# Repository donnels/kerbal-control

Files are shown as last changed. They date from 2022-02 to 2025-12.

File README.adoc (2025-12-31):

= image index
:toc:
[[2022-02-18T14-46%3A09-576Z.png]]

.2022-02-18T14-46%3A09-576Z.png

[[ISP_Voltage.png]]
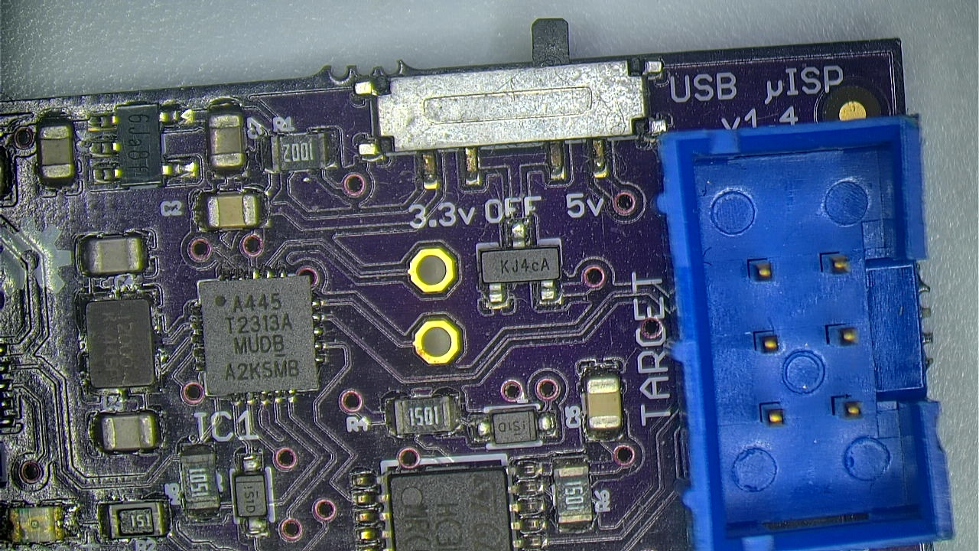
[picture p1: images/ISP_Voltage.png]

.ISP_Voltage.png

[[ISP_pinout.png]]
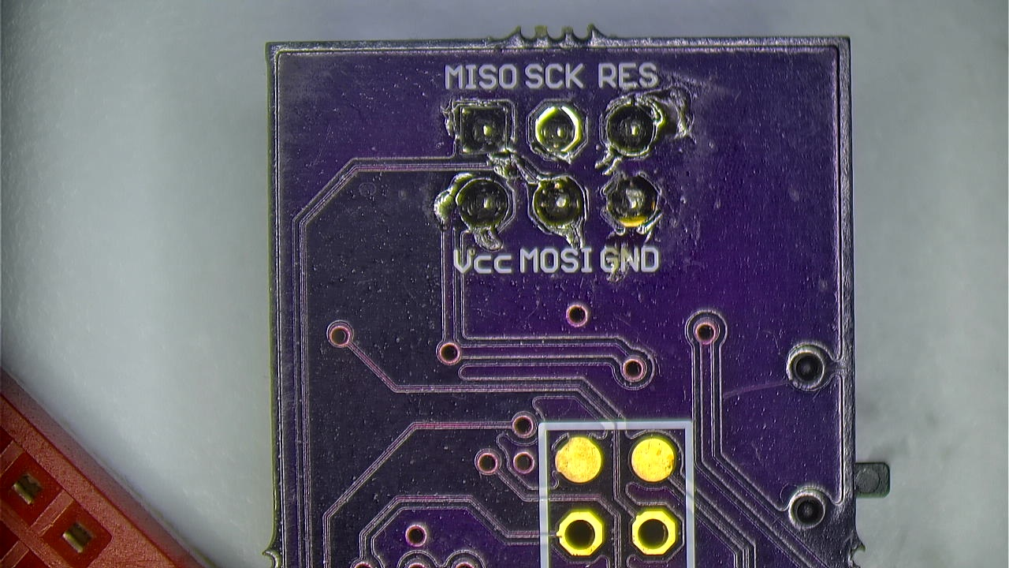
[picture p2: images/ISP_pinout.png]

.ISP_pinout.png

[[Kerbal.png]]
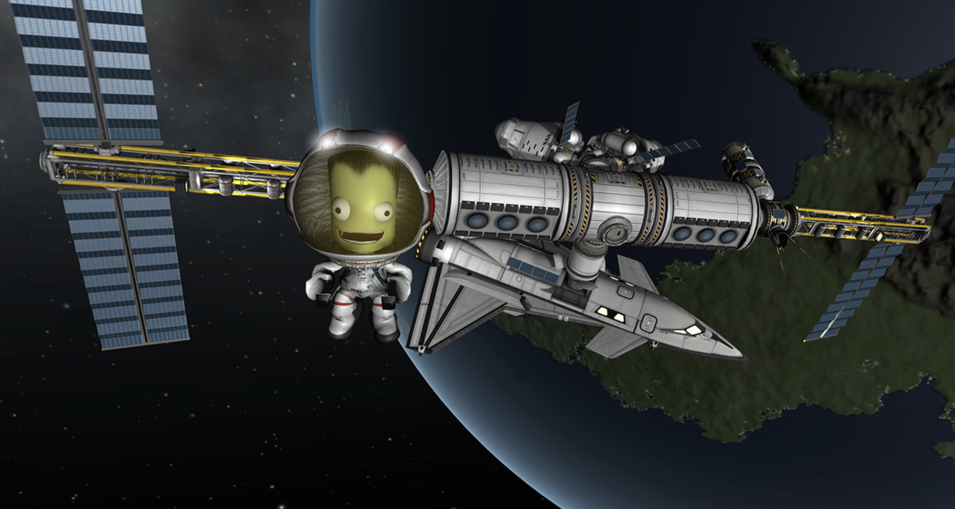
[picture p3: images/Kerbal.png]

.Kerbal.png

[[arduino-pro-micro-5v-pinout.png]]
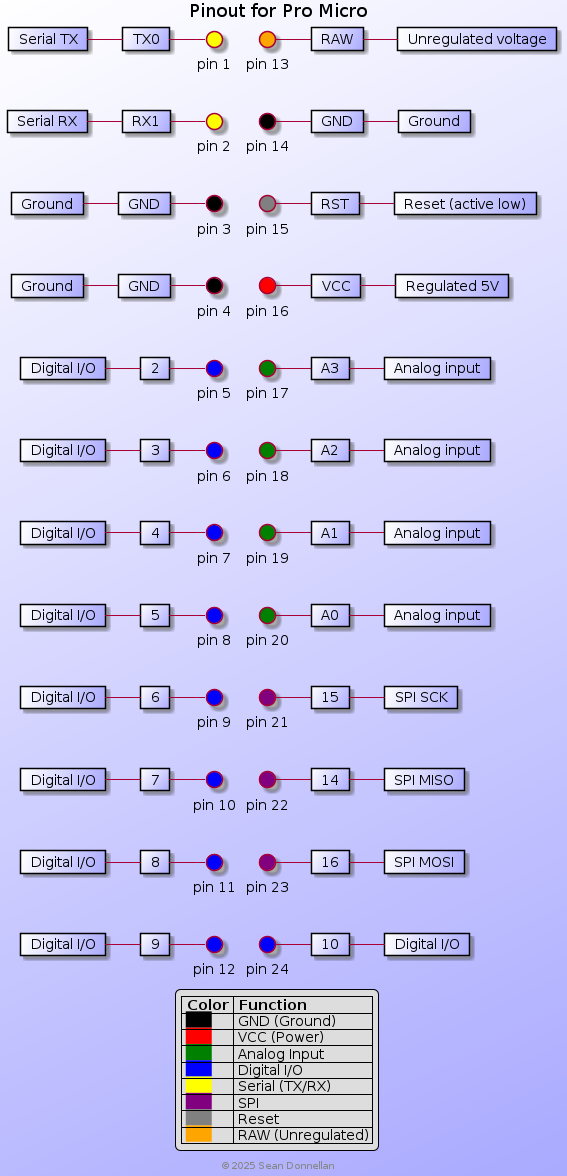
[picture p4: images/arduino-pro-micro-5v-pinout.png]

.arduino-pro-micro-5v-pinout.png

[[arduino-pro-micro-5v.png]]
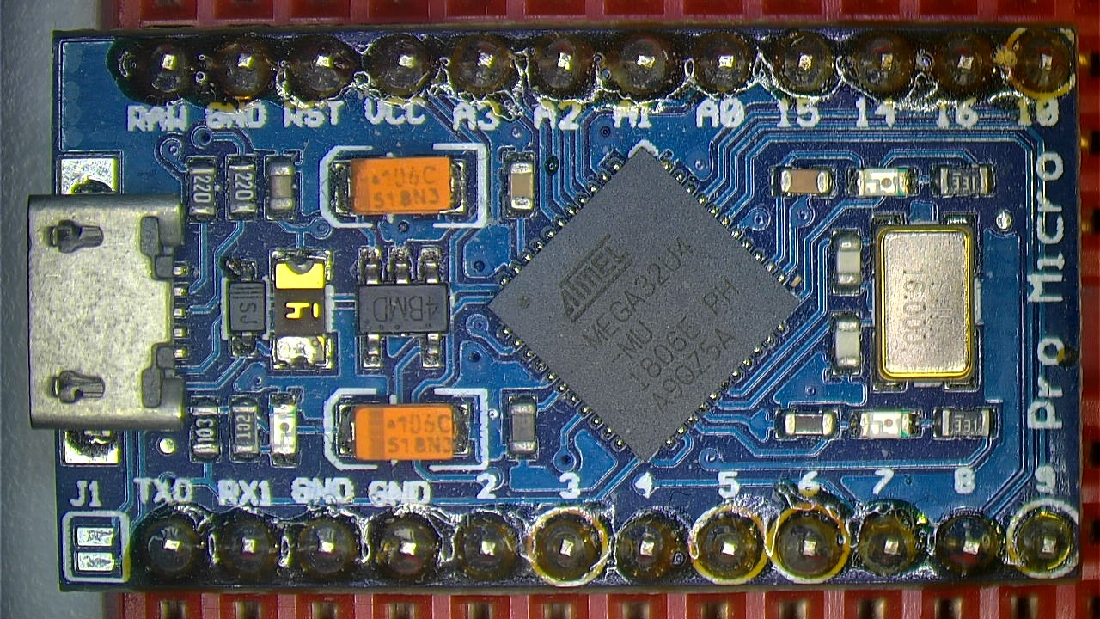
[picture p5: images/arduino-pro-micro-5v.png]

.arduino-pro-micro-5v.png

[[arduino-pro_micro_isp_schematic.png]]
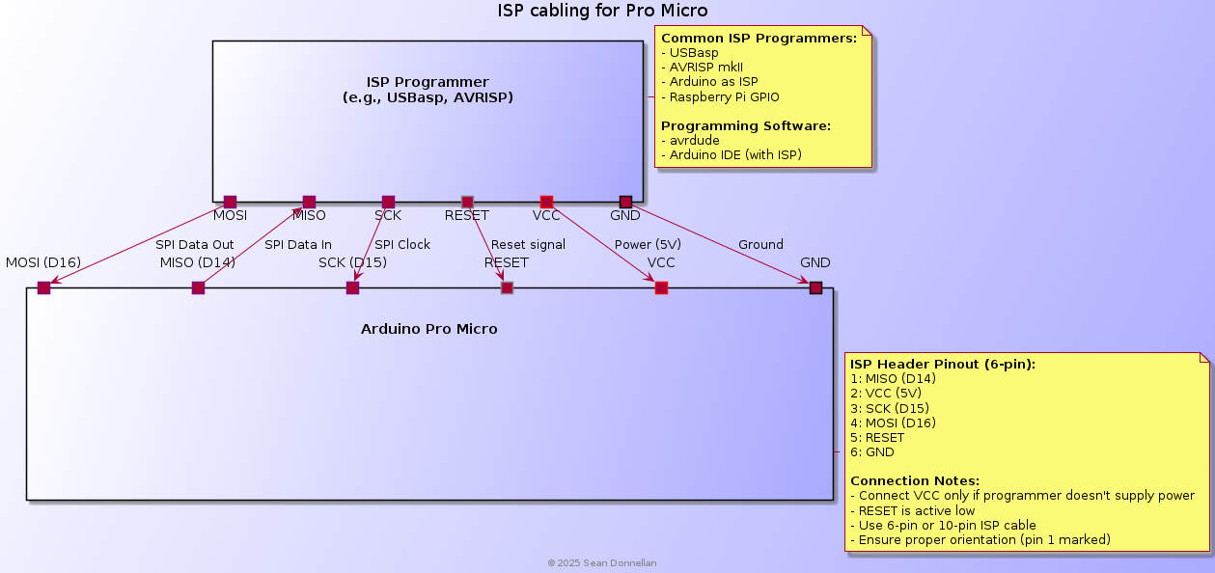
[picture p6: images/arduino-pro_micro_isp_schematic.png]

.arduino-pro_micro_isp_schematic.png

[[bounce.png]]
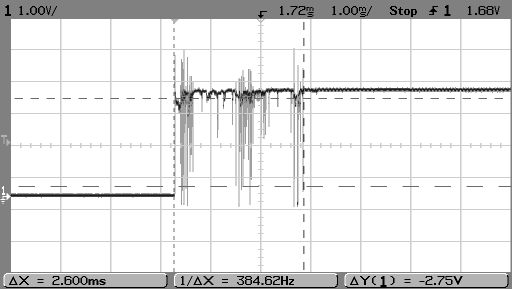
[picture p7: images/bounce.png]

.bounce.png

[[cherry-keycap-holder.png]]
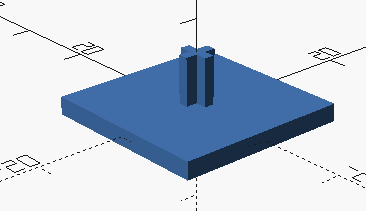
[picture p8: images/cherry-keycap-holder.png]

.cherry-keycap-holder.png

[[debounce.png]]
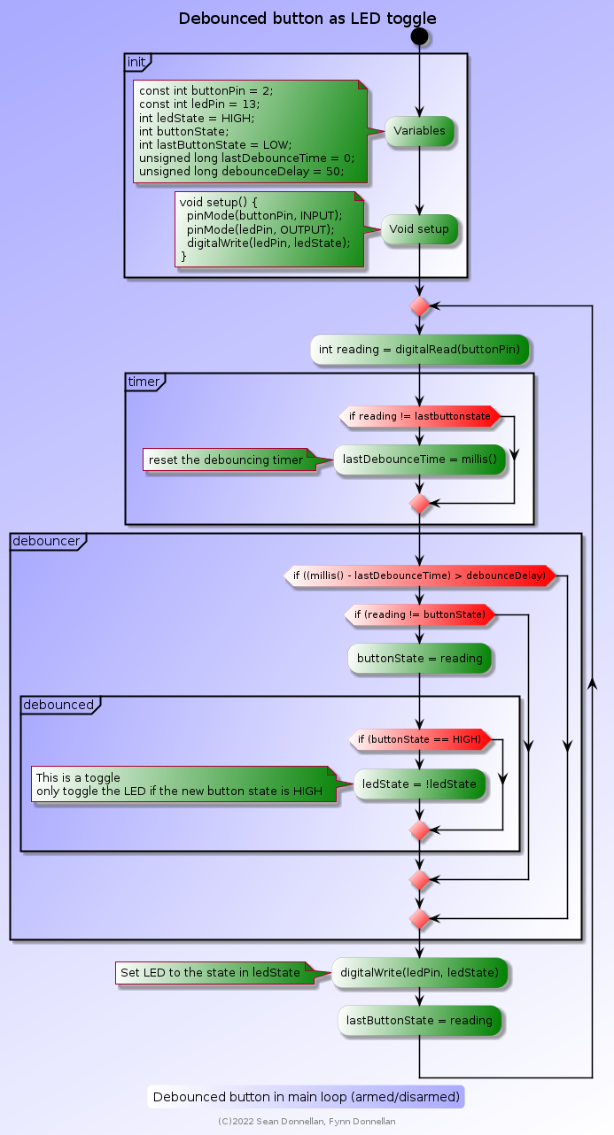
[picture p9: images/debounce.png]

.debounce.png

[[debounce2.png]]
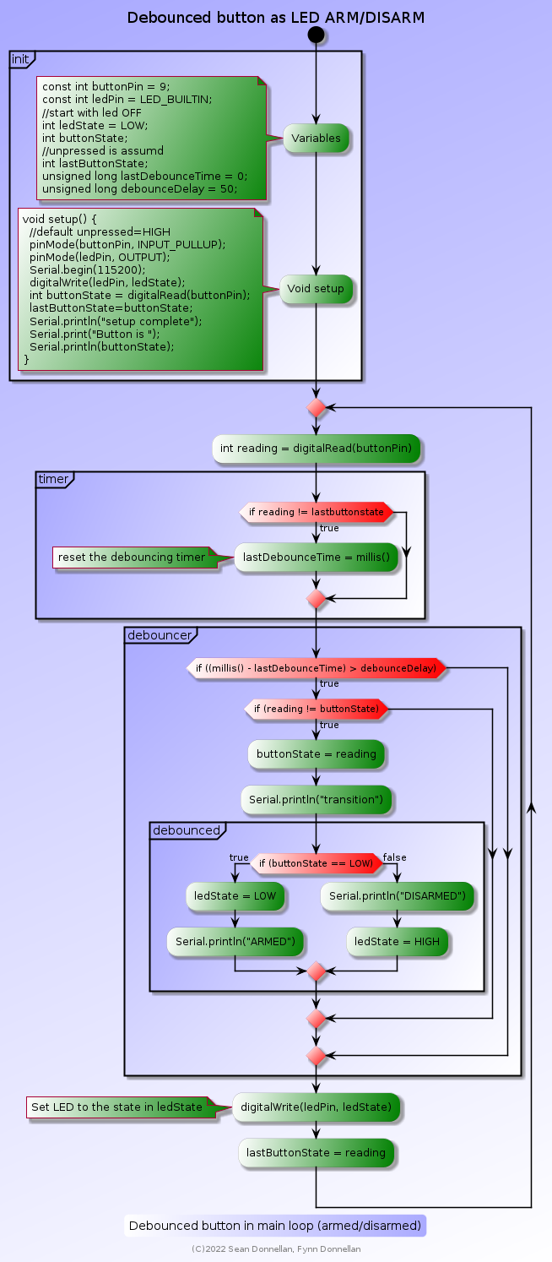
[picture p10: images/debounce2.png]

.debounce2.png

[[resistor-10kohm.png]]
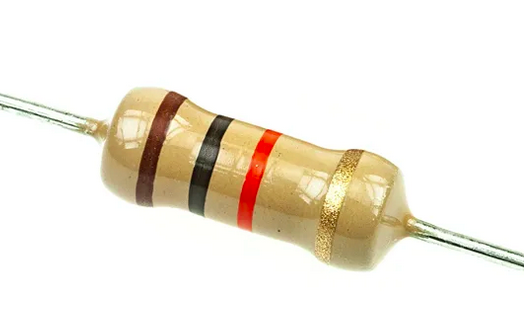
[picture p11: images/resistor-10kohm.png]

.resistor-10kohm.png

[[Button-Triger-stage.jpeg]]
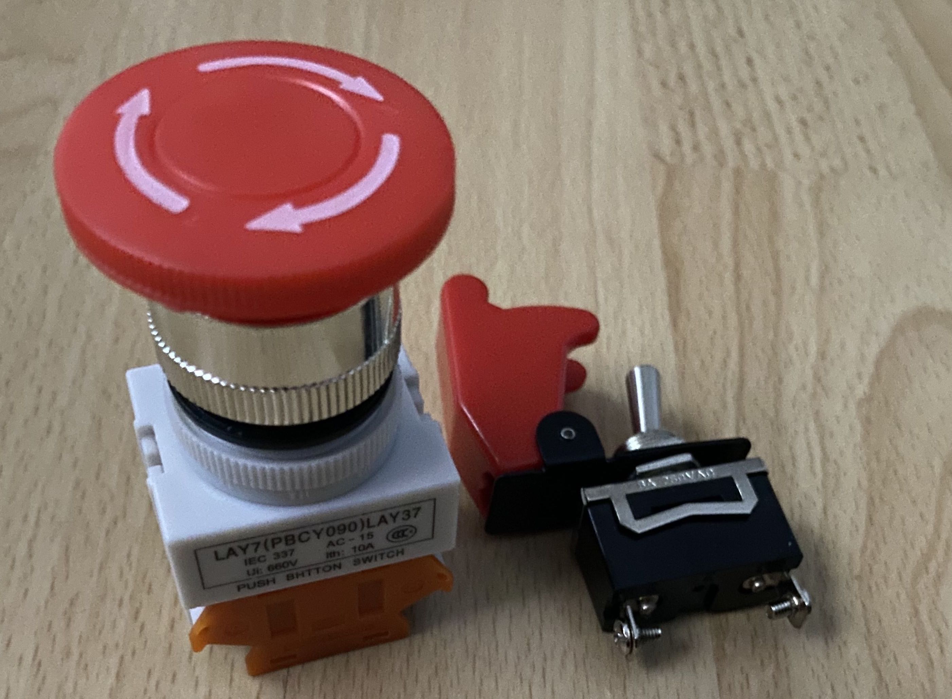
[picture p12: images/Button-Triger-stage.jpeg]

.Button-Triger-stage.jpeg

[[Prototype-led-ring-and-strip.jpeg]]
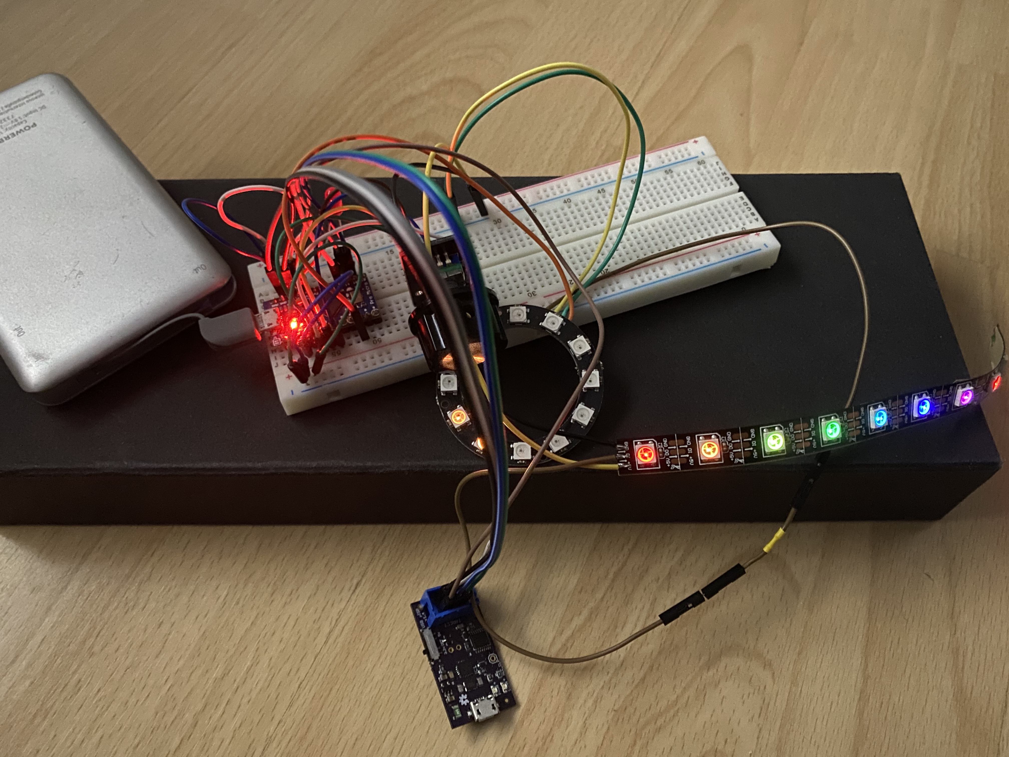
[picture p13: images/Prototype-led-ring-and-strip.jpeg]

.Prototype-led-ring-and-strip.jpeg

[[keyAndCapMokup.jpeg]]
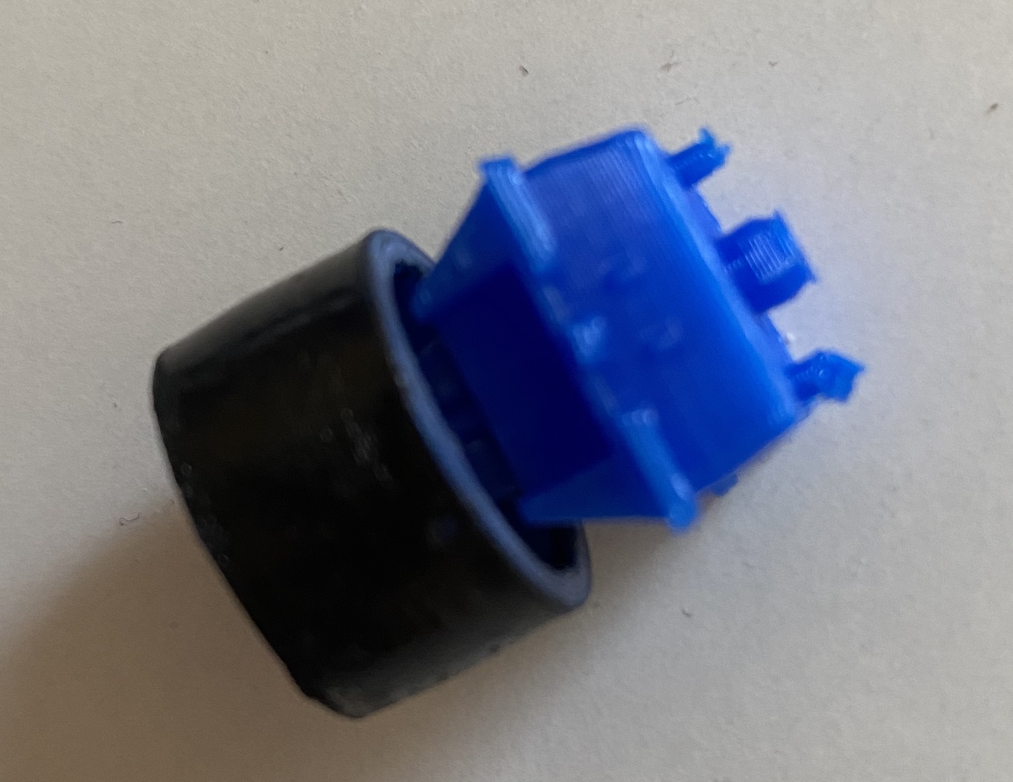
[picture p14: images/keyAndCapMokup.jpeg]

.keyAndCapMokup.jpeg

[[keycap-sanded.jpeg]]
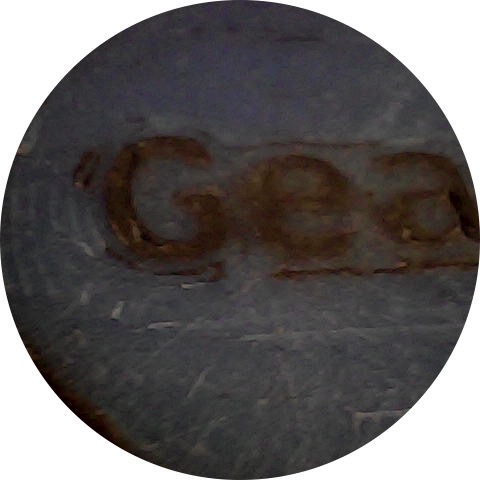
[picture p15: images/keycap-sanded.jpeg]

.keycap-sanded.jpeg

[[keycaps.jpeg]]
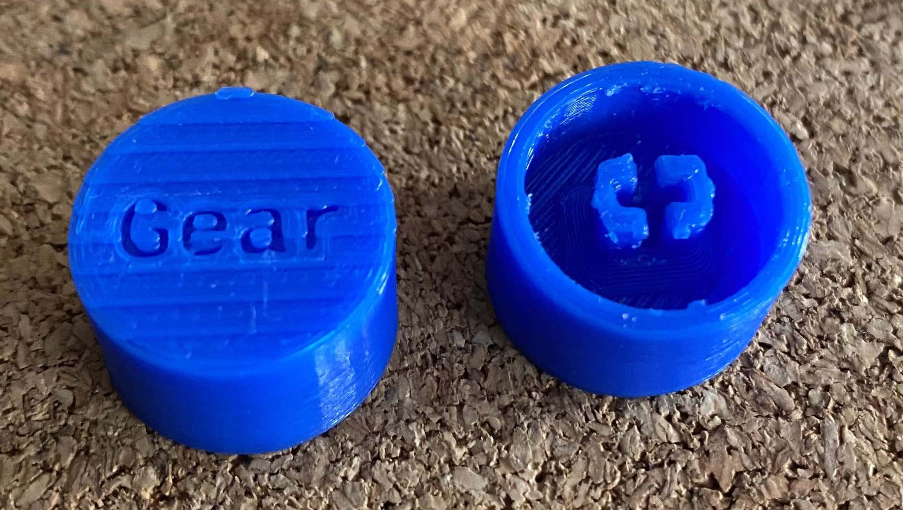
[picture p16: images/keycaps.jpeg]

.keycaps.jpeg

[[sand-paint-sand.jpeg]]
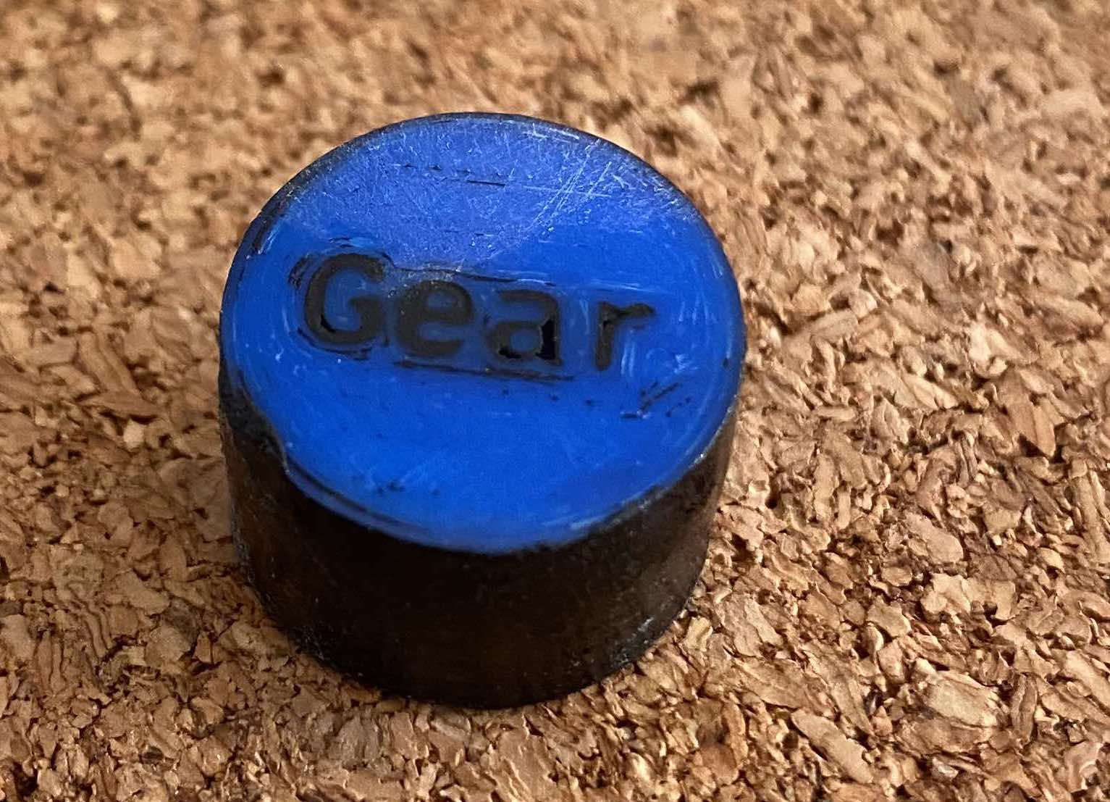
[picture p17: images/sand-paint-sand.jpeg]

.sand-paint-sand.jpeg

[[v2PlusButtons.jpeg]]
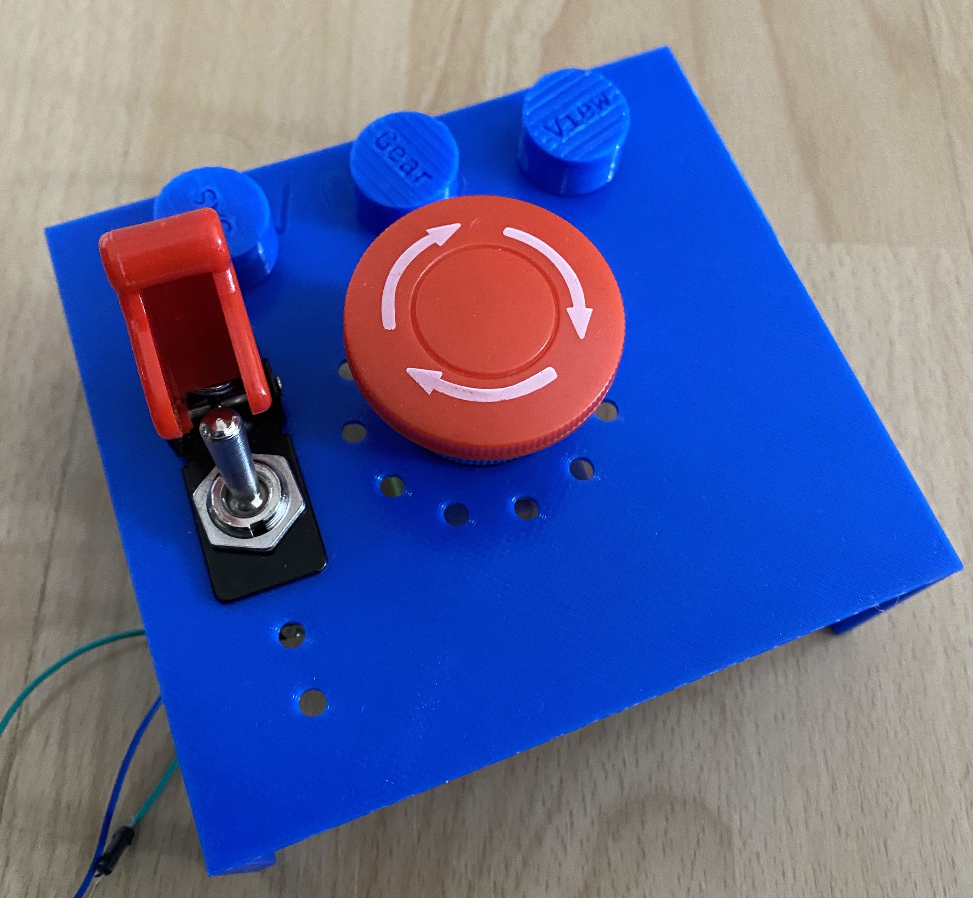
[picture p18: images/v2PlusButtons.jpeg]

.v2PlusButtons.jpeg

[[arduino-pro-micro-5v-pinout.svg]]

.arduino-pro-micro-5v-pinout.svg

[[arduino-pro_micro_isp_schematic.svg]]

.arduino-pro_micro_isp_schematic.svg

[[debounce.svg]]

.debounce.svg

[[debounce2.svg]]

.debounce2.svg

[[kerbal_ctrl_box_prototype.svg]]

.kerbal_ctrl_box_prototype.svg

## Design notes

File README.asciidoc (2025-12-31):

= kerbal-control
:author: Sean Donnellan, Oscar Donnellan, Fynn Donnellan
:toc: right
:sectnums:
:sectnumlevels: 5
:toclevels: 5
:data-uri: false
:doctype: article
:icons: font
:pdf-page-size: A4
:source-highlighter: rouge
:title-page:

== About this document

.HTML version
* link:https://donnels.github.io/kerbal-control/README.html[^]

.PDF version
* link:https://donnels.github.io/kerbal-control/README.pdf[^]

.Github source
* link:https://github.com/donnels/kerbal-control[^]

== Starting point
A project to add some more control to the PS5 Kerbal simulation.

.Screenshot from www.kerbalspaceprogram.com


* link:https://www.kerbalspaceprogram.com/[^]

After installing Kerbal on the PS5 and playing it for a while it quickly became clear that the controllers alone are not enough to enjoy the game.
The search began to find some way of improving things.
Kerbal allows control via the PS5 controllers AND via keyboard and mouse.
This means it should be possible to add some easy toggles/ switches/ rotary encoders to pass information to the game.
The first switch would be the space bar which kerbal uses to trigger stages.

While this is being developed for Kerbal it is generally a keyboard and can just as easily be used for many other applications, including video conferences.

=== kerbal key bindings
The following is a list of key bindings we can work with.

.Key bindings for Kerbal
* link:https://wiki.kerbalspaceprogram.com/wiki/Key_bindings[^]

The first key will be the space key to launch rockets.

=== Arduino - pro micro (5V)
Initial choice for a prototype is the AVR ATmega32u4 8-bit microcontroller which has a USB controller and can be used as both a keyboard and mouse if required.

"The Pro Micro is an Arduino-compatible microcontroller board developed under an open hardware license by Sparkfun. Clones of the Pro Micro are often used as a lower-cost alternative to a Teensy 2.0 as a basis for a DIY keyboard controller/converter when a lower number of pins would suffice."
-- https://deskthority.net/wiki/Arduino_Pro_Micro

.Pro micro 5v board


.Pro Micro Pinout


.Pro Micro ISP connections


The above figure shows the connections required to program the pro micro via ISP if the usb programming is failing.

[IMPORTANT]
====
During ISP programming, the Pro Micro board requires external power. Connect the board to a USB power source (computer, wall adapter, etc.) as the Raspberry Pi Zero does not provide sufficient power through the ISP programmer alone. Without external power, you may see "device signature = 0x000000" errors.
====

[NOTE]
====
When you have one or two different ones floating around it's easy to forget which is which. Measure the voltage between GND and VCC, with USB powered up, to be sure you have the 5V version. Don't let the magic smoke out by connecting the wrong voltage.
====

=== WS2812 LEDs
Because it's always good to have status LEDs and the WS2812 is both easy to get and has good libraries, with fastled and adafruit, it's the first choice. 

.Fastled
* link:https://github.com/FastLED/FastLED[^]
* link:https://fastled.io/[^]

The fastled library looks like a good choice.
The WS2812 LED rings I have are not tightly packed with LEDs but will suffice.
As I have a few WS2812 strips and a few WS2812 rings the choice went towards the WS2812 to be able to mix the strip and ring. In a first test I had accidentally used an RGBW ring which showed up that the fastled library can't handle them well so WS2812 is the choice now.

== Step 1 - First prototype
To get started I went to an example for LEDs to be able to later set a LED with a key/button.

.First LED example (arduino IDE)
[source%linenums, c++]
----
include::./src/fastled-test/fastled-test.ino[]
----

[NOTE]
====
The first test looks good and was tested on a 5v pro micro.
The prototype uses a strip with ten LEDs attached to a ring with 12 LEDs.
====

.Initial breadboard prototype with WS2812 ring and strip


The above code runs a LED around the ring and sets static colours on the strip.
A good start.
The animation works with delay which is probably not a good solution but works fine for a first test.

== Step 2 - Attach a button to trigger a stage

Since this will be starting rockets let's make it feel that way.
Just the space bar and maybe a toggle to arm it.

.Arduino reference
* keyboard
** link:https://www.arduino.cc/reference/en/language/functions/usb/keyboard/[^]
* Button
** link:https://www.arduino.cc/en/Tutorial/BuiltInExamples/Button[^]
* State change detection
** link:https://www.arduino.cc/en/Tutorial/BuiltInExamples/StateChangeDetection[^]

.Resistor for pull down

We will need to pull down/up the pin for the button so the above resistor is included to show an example 10K Ohm resistor. The pro micro may have inbuilt pull up/down resistors but that has to be checked. Pulling a line up or down endures it is always in a defined state and that it reacts quickly so that it is highly recommended even for testing.

.first buttons


The big red button is to trigger a stage and the toggle switch is to arm it. In this case we will soft arm the bitton as opposed to disconnecting it directly. 

.Very draft UI design


=== Bouncy Bouncy
Why all the fuss about bounce? And what is it?

* link:https://en.wikipedia.org/wiki/Switch[^]

.Example of bounce from the wikipedia


.activity diagram to show the flow


==== Interrupts
"The Pro Micro has five external interrupts, which allow you to instantly trigger a function when a pin goes either high or low (or both). If you attach an interrupt to an interrupt-enabled pin, you'll need to know the specific interrupt that pin triggers: pin 3 maps to interrupt 0 (INT0), pin 2 is interrupt 1 (INT1), pin 0 is interrupt 2 (INT2), pin 1 is interrupt 3 (INT3), and pin 7 is interrupt 4 (INT6)."
-- https://learn.sparkfun.com , pro micro hookup guide

.Example interrupt driven routine debounced
[source%linenums, c++]
----
void my_interrupt_handler()
{
  static unsigned long last_interrupt_time = 0;
  unsigned long interrupt_time = millis();
  // If interrupts come faster than 200ms, assume it's a bounce and ignore
  if (interrupt_time - last_interrupt_time > 200)
  {
    ... do your thing
  }
  last_interrupt_time = interrupt_time;
}
----

The above short section shows a debounced interrupt that uses millis instead of delays.
The important thing here is that if we debounce with delays we stall the whole loop so that if we have a LED animation or something else running it get's stalled. Using millis allows the rest to keep running.

Let's see if some of the above works.

=== first iteration
.initial tests
[source%linenums, c++]
----
include::./src/button-test/button-test.ino[]
----

[NOTE]
====
The first test looks good and was tested on an arduino UNO.
====

The above code works as a debounced latching button.
The aim though is to read a debounced button and to read it's state changes.

.What we really need
* ONLY when the button is pressed
** output state ONCE
* When button is released
** Output state once

=== Second iteration

.activity diagram to show the flow


.Second button test non latching (armed/disarmed)
[source%linenums, c++]
----
include::./src/button-test2/button-test2.ino[]
----

[NOTE]
====
This works and it was tested on an arduino uno.
Serial monitor was used to check the function.
====

== Step 3 - bring things together to see how the loop runs with buttons

.Integrated controller with LEDs, arm/disarm button, and stage button
[source%linenums, c++]
----
include::./src/kerbal-controller/kerbal-controller.ino[]
----

This MVP integrates LEDs for status, debounced buttons, and keyboard emulation for staging.

== Step 4 - rotary encoders

.An initial example with interrupts
* link:https://gist.github.com/dkgrieshammer/66cce6ec92a6427c16804df84c22cc83[^]

[appendix]
== Requirements

.Initial list of requirements
* Control Kerbal on PS5
** Via USB(A) keyboard interface
*** Use big red button with latch for stages
** Must show actions/button presses
*** WS2812 for key status changes red/green/etc
** Add some safety toggles (arm/disarm)
*** A classic toggle with red cover
** Control 
*** Stage trigger (space bar)
*** SAS (on/off) (t)
*** gear (up/down) (g)
*** time warp (rotary +/-) (.,)
*** throttle (rotary +/-) (shift,cntrl)
*** motors (on/off) (x,k)
*** View (inside/outside) ???

This should cover the most required buttons and should be possible without multiplexing.

[appendix]
== Interface design thoughts
Since the first button is a big red one with a latch it make sense to also show what state it's in.
Adding a LED ring around it sounds like a good idea.
Adding a LED ring around a rotary encoder also sounds like a good idea (optional).

=== Arm/disarm toggle
toggle disarmed:: disArm led LED red(?), latch ring red blink(?)
toggle armed:: ARM led green, latch ring green

=== Triger stage button
unlatched:: ring green
press:: ring red for 1 sec
latched:: Ring orange

[appendix]
== 3d printed test stand
The Aim here is to have a stand to mount the buttons and LEDs to while testing.
After testing this can be used as a template for drilling.
Also this can later be adapted to make a holder for the led ring and potentially the LEDs that can be mounted under the lid of the box.

.OpenScad source
[source%linenums,openscad]
----
include::./3d/protoTypeStand.scad[]
----

.3d stand STL (second iteration)
image::./3d/Screenshot 2022-02-07 at 20.28.38.png[]

The first test fitting worked well to show up some room for improvement:

* Toggle switch moved left and down
* legs longer
* LED ring proper Radius

.Prototype with v2


The intial V2 print populated with additional key caps placed to show approximate position of possible keys for later.

[appendix]
== openscad library for custom keycaps

the following library allows the creation of keycaps in different sizes and shapes.
since we'll be drilling the holes for any buttons round keycaps for cherry mx switches looks like a good option for keys.

* link:https://github.com/rsheldiii/KeyV2[^]

As there is a broken backlit keyboard lying around it will probably find itself devoid of some switches for this if they fit.

=== Raw keycap print

.draft keycaps with inlayed text for cherry mx (round)


.Patch file for the above repo to make round keycaps
[source,DIFF]
----
include::./3d/keycaps.patch[]
----

The above keycaps fit the MX clone switches we have and will work for prototyping.
To make them look like really high quality switches some post processing will be required.
This was a quick and dirty print in low resolution for initial testing.

.Potential problem with clearance


Just to be sure the above mokup key was printed and it turns out there might be a clearance problem with the switch housing.
It was not as apparent when test fitting to the switch as it was between other keys.

=== Keycap post processing

* One variant might be to print Caps with no inlay
** Sand with 1000+ grit 
** Paint
** Cover with tape
** Laser inlay through tape
** Paint inlay
** Remove tape
* Another variant might be to print in the target colour with inlay
** Paint inlay
** Sand with 1000+ grit

The above approaches need to be tested but since printing key caps is easy enough now this also should be easy enough.
It might involve printing a positioning guide to help align any laser cutting and that can be done at a later stage if required.

==== Sand - Paint - Sand
.Sand-Paint-Sand (without waiting for the paint to dry)


From this initial very fast test it looks like the laser option is getting more likely.
Because the keycap is sloped the sanding uncovers the slope lines and, because we're hand sanding, unevenly.
This leaves a slight artefact that would ideally beg for a coat of paint which would cover the inlay again so the simple sand - paint - sand option doesn't look that good.
The painted part did look good though even if it didn't have time to dry.
One question is what will the laser do with PLA.
One question though is answered: The inlay looks good and sanding works well if combined with paint.

.A closer look at the sanded surface (with a Wifi otoscope)


The above macro photo shows that PLA doesn't look that nice when sanded. There was an initial hope that heat might help smooth it again.
The result of heat to the above key, while not shown, was uneven and unsatisfactory and probably requires more skill to do well so that the 2 minutes spent might have turned something better up if they had been 15 minutes. 
Still the result of the 2 minutes with a gas torch showed that the layer lines will be highlighted through heating so that it probably only makes good sense for a flat surface or one with finer layer lines more closely spaced.
There is probably room for experiments with solvents here also as others have had success with that.
The laser option looks to probably be the one with a higher degree of repeatability and probably a better surface finish also through sanding and painting and sanding and painting and then lasing through tape and filling in the inlay with the tape in place.
The laser will require some help with positioning so a printed MX key stalk on a positioning plate for a wainlux K6 laser will probably be designed and printed to assist as otherwise the sloped keys are likely to be misaligned through rotation more than X/Y position.
Maybe something like this: link:https://www.thingiverse.com/thing:4712402[^]

==== Laser engraver approach
As described above using a laser to engrave the keycaps might be the road to a clean look.

The first step is to print a cherry keycap holder.

===== Cherry keycap holder
This is a requirement to be able to position the key caps repeatably.
And this would have been good for the spray painting of the first cap too (maybe a bit higher).
Since the keycap is slightly slanted this holder should probably account for that (V1 doesn't).
The laser engraving should work fine none the less and if not the slant will be adapted to the holder also.

.Openscad source
[source,OPENSCAD]
----
include::./3d/cherry_keycap_holder.scad[]
----

.Screenshot of the keycap holder


.And the 5° tilted V2
 

.The next steps (ToDo)
* Print a blank keycap
* Repeat as required:
** Sand the keycap (1000 Grit or higher)
** Spray paint the cap (1st coat with filler?)
* Mask the cap with tape
* Laser engrave
* Fill inlay
* Remove tape
* Optionally add clear coat 

[appendix]
== Current Progress and Next Steps

Code written. Compiled clean. USB fails. ISP wired. Ready to burn. Board waits. Test next.

- MVP controller code integrated in [`kerbal-controller.ino`](src/kerbal-controller/kerbal-controller.ino).
- Compiled successfully on Pi Zero using Arduino CLI.
- USB programming blocked by hardware issues; switched to ISP via avrdude.
- Wiring: Pi GPIOs to Pro Micro ISP header for SPI programming.
- Next: Upload via ISP, test in Kerbal Space Program.

== Development Pipeline

This project uses a split development workflow between a host machine (Steamdeck, with VS Code) and a Raspberry Pi (used for compiling and uploading to the Arduino Pro Micro). This allows for convenient editing and version control on the host, while leveraging the Pi for hardware interfacing and programming.

=== Workflow Steps

. Edit code on the host (Steamdeck) using VS Code or your preferred editor.
. Save changes locally.
. Transfer the updated code to the Raspberry Pi using `scp`:
+
----
scp /path/to/src/kerbal-controller/kerbal-controller.ino sean@arduinoworkstation.fritz.box:/home/sean/kerbal-control/
----
. SSH into the Raspberry Pi:
+
----
ssh sean@arduinoworkstation.fritz.box
----
. On the Pi, compile the code using Arduino CLI:
+
----
cd /home/sean/kerbal-control
/home/sean/bin/arduino-cli compile --fqbn arduino:avr:leonardo src/kerbal-controller/kerbal-controller.ino
----
. Upload the compiled code to the Arduino Pro Micro:
+
----
/home/sean/bin/arduino-cli upload -p /dev/ttyACM0 --fqbn arduino:avr:leonardo src/kerbal-controller/kerbal-controller.ino
----
. (Optional) Monitor serial output for debugging:
+
----
screen /dev/ttyACM0 9600
----

This pipeline allows for rapid iteration: edit on the host, transfer, compile/upload on the Pi, and test on the Arduino.

=== Sequence Diagram

[plantuml, dev-pipeline-sequence, svg]
----
include::plantuml/dev-pipeline-sequence.puml[]
----

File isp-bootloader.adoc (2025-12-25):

= Burning a New Bootloader via ISP
:toc:
:sectnums:

This guide describes how to burn a new bootloader onto the Arduino Pro Micro using ISP (In-System Programming), as required for board recovery or when USB programming fails.

== Prerequisites
* [ ] Raspberry Pi (Zero or other) with GPIO header
* [x] USBtinyISP or similar ISP programmer
* [x] Arduino Pro Micro (5V)
* [x] Required wiring (see schematic)
* [x] External USB power for Pro Micro (critical!)
* [x] avrdude installed on the Pi
* [x] Caterina-Leonardo bootloader hex file (from Arduino IDE or online)

== Wiring
- Connect Pi GPIOs (via ISP programmer) to Pro Micro ISP header:
  - MISO, MOSI, SCK, RESET, VCC, GND
- Connect Pro Micro to USB power (do NOT rely on Pi power alone)

== Steps
. Power the Pro Micro via USB (do not skip!)
. Connect ISP programmer to Pi and Pro Micro.
. On the Pi, run:
+
----
avrdude -c usbtiny -p m32u4 -U flash:w:Caterina-Leonardo.hex:i -U lfuse:w:0xff:m -U hfuse:w:0xd8:m -U efuse:w:0xcb:m
----
. Wait for avrdude to complete without errors.
. Disconnect ISP and USB, reconnect Pro Micro to host via USB.
. Board should now be programmable via USB again.

== Troubleshooting
- If you see `device signature = 0x000000`, the Pro Micro is not powered. Connect USB power.
- Double-check all wiring and fuse settings.
- See README for more details and schematic images.

== References
- https://learn.sparkfun.com/tutorials/pro-micro--fio-v3-hookup-guide#installing-bootloader
- https://www.arduino.cc/en/Hacking/Bootloader

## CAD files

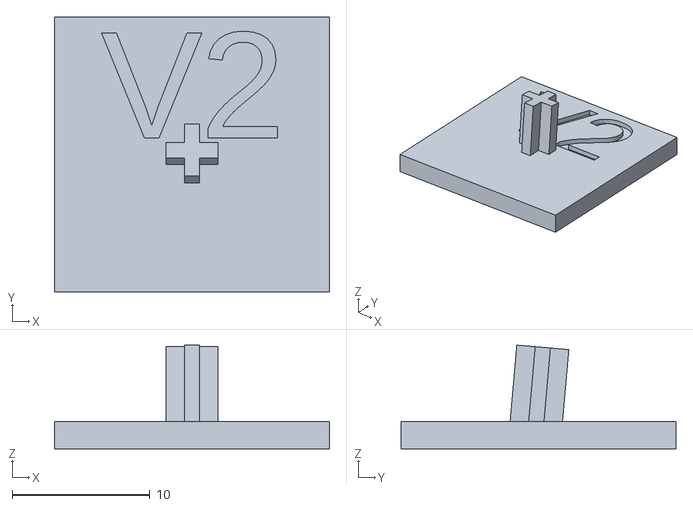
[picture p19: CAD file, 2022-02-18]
3d/cherry_keycap_holder-v2.stl
20.0 x 20.0 x 7.55

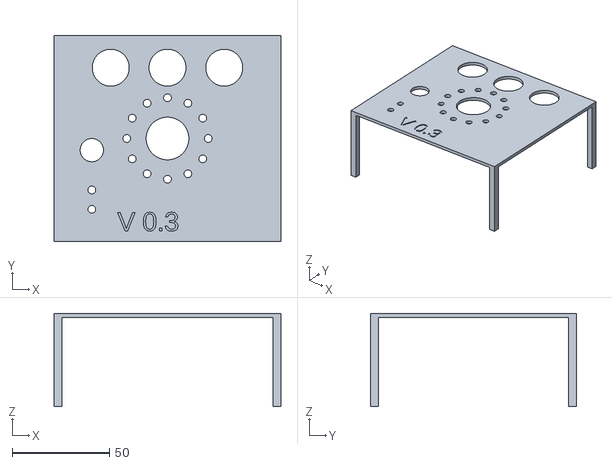
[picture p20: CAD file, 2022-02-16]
3d/protoTypeStand.stl
117.0 x 106.0 x 48.0

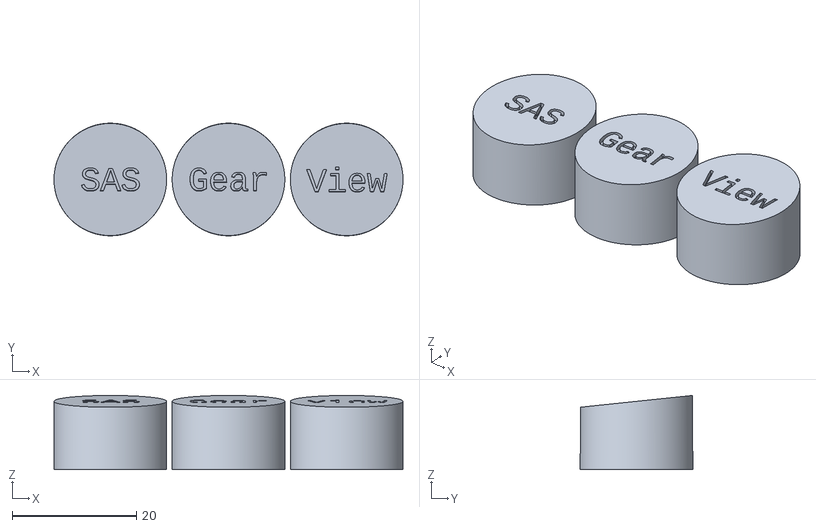
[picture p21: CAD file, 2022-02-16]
3d/keys.stl
56.3 x 18.2 x 11.9

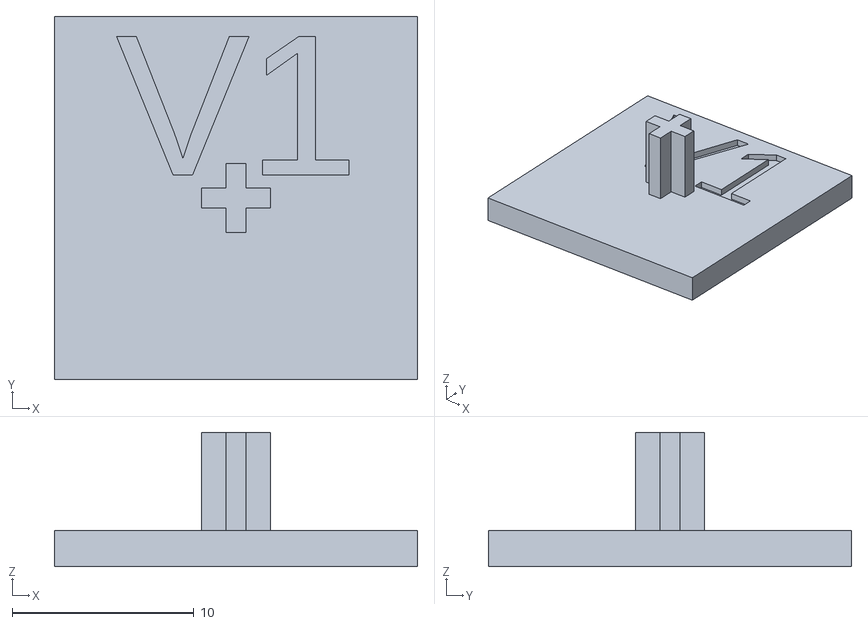
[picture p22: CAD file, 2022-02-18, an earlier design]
3d/cherry_keycap_holder.stl
20.0 x 20.0 x 7.40

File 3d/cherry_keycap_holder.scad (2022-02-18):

// Cherry MX keycap holder for laser engraving

cross_x = 4;
cross_y = 1.31;
cross_z = 3.6;
cross_tolerance = 0.2;
plate_z = 2 ;
key_slope = 5 ; // 5 degrees approx.

//versioning
letter_size = 8;
letter_height = 2;
font = "Liberation Sans";
Version = "V2" ;

module letter(l) {
	linear_extrude(height = letter_height) {
		text(l, size = letter_size, font = font, halign = "center", valign = "center", $fn = 16);
	}
}
difference() {
    cube([20,20,plate_z],center=true);
    translate([0,5,plate_z/4]) letter(Version);
}
translate([0,0,plate_z/2+cross_z/2]) rotate([-5,0,0]) {
    cube([cross_y-cross_tolerance, cross_x-cross_tolerance, cross_z*2], center=true);
    cube([cross_x-cross_tolerance, cross_y-cross_tolerance, cross_z*2], center=true);
}

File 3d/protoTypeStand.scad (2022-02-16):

$fn=360;
// mm for slyrs box
topWidth=117;
topDepth=106;
topThick=2;
pillar=4;
height=46;
BigRedButtonD=22;
ToggleD=12;
WS2812D=4;
WS2812RingR=42/2;
numLEDs=12;
//versioning
letter_size = 10;
letter_height = topThick/2;
font = "Liberation Sans";
Version = "V3" ;

module letter(l) {
	linear_extrude(height = letter_height) {
		text(l, size = letter_size, font = font, halign = "center", valign = "center", $fn = 16);
	}
}

module legs() {
	//Legs are only needed during prototype phase
	translate([0,0,0]) cube([pillar,pillar,height]);
	translate([topWidth-pillar,0,0]) cube([pillar,pillar,height]);
	translate([topWidth-pillar,topDepth-pillar,0]) cube([pillar,pillar,height]);
	translate([0,topDepth-pillar,0]) cube([pillar,pillar,height]);
}
module boxTop() {
	cube([topWidth,topDepth,topThick]);
}

module bigRedButton() {
	// Big red Button
    cylinder(h=topThick+2,d=BigRedButtonD);
}

module toggleSwitch() {
	// toggle switch
    cylinder(h=topThick+2,d=ToggleD);
}

module cherryKey() {
	// toggle switch
    cherryKeycap=18;
    cherryClearance=cherryKeycap+1;
    cylinder(h=topThick+2,d=cherryClearance);
}

module LED() {
	// disarmed LED
    cylinder(h=topThick+2,d=WS2812D);
}

module LEDRing() {
	//LED ring
	for ( i = [0 : 360/numLEDs : 360] ){
            rotate([0, 0, i]) translate([0, WS2812RingR, -1]) LED();
    }
}
module versioning() {
	//text
    letter(Version);
}

module testStand() {
	legs();
	translate([0,0,height]) 
	difference() {
		boxTop();
		translate([topWidth/2,topDepth/2,-1]) bigRedButton();
		translate([topWidth/6,topDepth/2-6,-1]) toggleSwitch();
		translate([topWidth/6,topDepth/4,-1]) LED();
		translate([topWidth/6,topDepth/4-10,-1]) LED();
        //3 keys with circular keycaps chery MX clones
        //keycaps have text on caps
        translate([topWidth*.25,topDepth-(19/2)-7,-1]) cherryKey();
        translate([topWidth*.5,topDepth-(19/2)-7,-1]) cherryKey();
        translate([topWidth*.75,topDepth-(19/2)-7,-1]) cherryKey();
		translate([topWidth/2,topDepth/2,0]) LEDRing();
		translate([topWidth/2-10,+10,(topThick/2)+.5]) versioning();
	}
}

testStand();


//add a right side with holes for rotary encoders or wait?
// wait?
// the side will have two rotary encoders
// one for Throttle and one for timewarp
// add Leds on the top ( + / toggle-Key / - ) 
// 3 LEDS for each encoder 

module ringHolder() {
    //module for led ring holder - DRAFT
    holderH=2;
    holderOutD=50;
    holderInD=35;
    holderFence=1;
    holderFenceOutD=holderOutD+holderFence;
    holderFenceInD=holderInD-holderFence;
    difference() {
        //holder ring
        difference () {
            cylinder(h=holderH+holderFence,d=holderFenceOutD);
            translate([0,0,-1]) cylinder(h=holderH+holderFence+2,d=holderFenceInD);
        }
        //led ring for subtraction
        translate([0,0,holderFence+1]) difference () {
            cylinder(h=holderH,d=holderOutD);
            translate([0,0,-1]) cylinder(h=holderH+2,d=holderInD);
        }
    }
}
//draft for now
//ringHolder();
//LEDRing();

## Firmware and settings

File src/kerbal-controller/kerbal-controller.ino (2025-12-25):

#include <FastLED.h>
#include <Keyboard.h>

// Pin definitions
#define LED_DATA_PIN 7
#define ARM_BUTTON_PIN 8
#define STAGE_BUTTON_PIN 9

// LED setup
#define NUM_LEDS 22
#define RING_LEDS 12
CRGB leds[NUM_LEDS];

// Button states
int armButtonState = HIGH; // HIGH = unpressed (pullup)
int lastArmButtonState = HIGH;
unsigned long lastArmDebounceTime = 0;

int stageButtonState = HIGH;
int lastStageButtonState = HIGH;
unsigned long lastStageDebounceTime = 0;

unsigned long debounceDelay = 50;

// System state
bool armed = false;
bool startup = true;
bool stagePressed = false;

void setup() {
  // LEDs
  FastLED.addLeds<NEOPIXEL, LED_DATA_PIN>(leds, NUM_LEDS);
  FastLED.setBrightness(10); // Low brightness
  updateLEDs();

  // Buttons
  pinMode(ARM_BUTTON_PIN, INPUT_PULLUP);
  pinMode(STAGE_BUTTON_PIN, INPUT_PULLUP);

  // Keyboard
  Keyboard.begin();

  // Serial debugging
  Serial.begin(9600);
  Serial.println("Kerbal Controller Started - Disarmed");
}

void loop() {
  handleArmButton();
  handleStageButton();
  
  // LED animation when armed
  if (armed && !stagePressed) {
    static unsigned long lastLEDChange = 0;
    static int activeLED = 6;
    if (millis() - lastLEDChange > 100) {
      for(int i=6; i<=10; i++) leds[i] = CRGB::Black;
      leds[activeLED] = CRGB::Green;
      activeLED = (activeLED >= 10) ? 6 : activeLED + 1;
      lastLEDChange = millis();
    }
  }
  
  // Blink LEDs 6-10 orange while stage pressed
  if (stagePressed) {
    static unsigned long lastBlink = 0;
    static bool blinkState = false;
    if (millis() - lastBlink > 200) {
      CRGB color = blinkState ? CRGB::Orange : CRGB::Black;
      for(int i=6; i<=10; i++) leds[i] = color;
      blinkState = !blinkState;
      lastBlink = millis();
    }
  }
  
  // Debug output every second
  static unsigned long lastDebug = 0;
  if (millis() - lastDebug > 1000) {
    Serial.print("Armed: ");
    Serial.print(armed ? "YES" : "NO");
    Serial.print(" | ARM switch: ");
    Serial.print(armButtonState == LOW ? "ON" : "OFF");
    Serial.print(" | STAGE button: ");
    Serial.println(digitalRead(STAGE_BUTTON_PIN) == LOW ? "PRESSED" : "RELEASED");
    lastDebug = millis();
  }
  
  FastLED.show();
}

void handleArmButton() {
  int reading = digitalRead(ARM_BUTTON_PIN);
  if (reading != lastArmButtonState) {
    lastArmDebounceTime = millis();
  }
  if ((millis() - lastArmDebounceTime) > debounceDelay) {
    if (reading != armButtonState) {
      armButtonState = reading;
      if (startup) {
        startup = false;
      } else {
        armed = (armButtonState == LOW);
        updateLEDs();
      }
    }
  }
  lastArmButtonState = reading;
}

void handleStageButton() {
  int reading = digitalRead(STAGE_BUTTON_PIN);
  if (reading != lastStageButtonState) {
    lastStageDebounceTime = millis();
  }
  if ((millis() - lastStageDebounceTime) > debounceDelay) {
    if (reading != stageButtonState) {
      stageButtonState = reading;
      if (stageButtonState == LOW && armed) {
        if (!stagePressed) {
          Keyboard.press(' '); // Spacebar for stage
          delay(10);
          Keyboard.releaseAll();
          flashStageLED();
          stagePressed = true;
        }
      } else if (stageButtonState == HIGH) {
        stagePressed = false;
      }
    }
  }
  lastStageButtonState = reading;
}

void updateLEDs() {
  if (armed) {
    fill_solid(leds, NUM_LEDS, CRGB::Black);
    leds[0] = CRGB::Green; // Toggle indicator
  } else {
    fill_solid(leds, NUM_LEDS, CRGB::Red);
  }
}

void flashStageLED() {
  // Flash ring red briefly
  for (int i = 0; i < RING_LEDS; i++) {
    leds[i] = CRGB::Red;
  }
  FastLED.show();
  delay(200);
  updateLEDs();
}

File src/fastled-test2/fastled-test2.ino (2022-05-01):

#include <FastLED.h>
//fastled stuff
#define NUM_LEDS 22
#define NUM_RING_LEDS 12
#define DATA_PIN 7
#define disarmed_LED 12
#define armed_LED 13
#define SAS_LED 14
#define rot1p_LED 15
#define rot1m_LED 16
#define rot1b_LED 17
CRGB leds[NUM_LEDS];

//button stuff
const int buttonPin = 8;      
//start with led OFF         
int armButtonState; 
//unpressed is assumd            
int lastarmButtonState;   
unsigned long lastDebounceTime = 0;  
unsigned long debounceDelay = 12;   
//LED brightness stuff
int brightness = 5;

void setup() { 
  //LED stuff
  FastLED.addLeds<NEOPIXEL, DATA_PIN>(leds, NUM_LEDS);
  FastLED.setBrightness(brightness);
  leds[disarmed_LED] = CRGB::Blue;
  leds[armed_LED] = CRGB::Black;
  leds[SAS_LED] = CRGB::Black;
  leds[rot1p_LED] = CRGB::Black;
  leds[rot1m_LED] = CRGB::Black;
  leds[rot1b_LED] = CRGB::Black;
  //spare
  leds[18] = CHSV(0, 255, 16);
  leds[19] = CHSV(63, 255, 16);
  leds[20] = CHSV(127, 255, 16);
  leds[21] = CHSV(255, 255, 16);
  //END LEDS
  FastLED.show();
  //button stuff
  //default unpressed=HIGH
  pinMode(buttonPin, INPUT_PULLUP);
  int armButtonState = digitalRead(buttonPin);
  lastarmButtonState=armButtonState;
  //The rest
  Serial.begin(115200);
  Serial.println("setup complete");
  Serial.print("Button is ");
  Serial.println(armButtonState);
}

void loop() {
  int reading = digitalRead(buttonPin);
  if (reading != lastarmButtonState) {
    lastDebounceTime = millis();
  }
  if ((millis() - lastDebounceTime) > debounceDelay) {
    if (reading != armButtonState) {
      armButtonState = reading;
      Serial.println("transition");
      if (armButtonState == HIGH ) {
        Serial.println("ARMED");
        leds[disarmed_LED] = CRGB::Red;
        leds[armed_LED] = CRGB::Black;
      } 
      else {
        Serial.println("DISARMED");
        leds[armed_LED] = CRGB::Green;
        leds[disarmed_LED] = CRGB::Black;;
      }
    }
  }

  FastLED.show();
  lastarmButtonState = reading;
}

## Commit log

2022-02-05 added led example
2022-02-05 added prototype
2022-02-05 first draft button read prog
2022-02-05 lets read the button first
2022-02-06 added button-test
2022-02-06 added resistor for pulldown
2022-02-06 changed the code for button-test to include a button press
2022-02-06 added debounce example with millis
2022-02-06 added openscad draft as test stand
    [protoTypeStand.scad, protoTypeStand.stl]
2022-02-06 scad updated
    [protoTypeStand.scad]
2022-02-07 version 0.2 stl
    [protoTypeStand.scad, protoTypeStand.stl]
2022-02-07 added v0.2 scad
    [protoTypeStand.scad]
2022-02-11 first button test with uno
2022-02-11 We changed the original debounce to a latching button because that worked
2022-02-12 added second button test
2022-02-12 added draft led ring holder for fun and profit
    [protoTypeStand.scad]
2022-02-14 changed button-test1 back to a latching button
2022-02-14 made button-test2 maybe work
2022-02-14 button-test2 works finally
2022-02-14 interrupt pins
2022-02-15 modularized things
    to make it clearer (and shorter)
    [protoTypeStand.scad]
2022-02-16 3d rendered keys for 1st keycap test
    [keys.stl]
2022-02-16 added the 3 holes for the top keys
    [protoTypeStand.scad, protoTypeStand.stl]
2022-02-16 holes added
    [protoTypeStand.scad]
2022-02-17 added prototype figure
2022-02-17 heat treatment
2022-02-17 added keycap holder
    [cherry_keycap_holder.scad]
2022-02-17 a bit of revision to the keycap holder for a version number
    [cherry_keycap_holder.scad]
2022-02-17 added todo for laser
2022-02-18 cropped and added stl
    [cherry_keycap_holder.stl]
2022-02-18 added tilted holder
    [cherry_keycap_holder.scad]
2022-02-18 v2 stl key holder
    [cherry_keycap_holder-v2.stl, cherry_keycap_holder.scad]
2022-02-20 Made fastledtest2 show the concurrent state of the arm/disarm button through LEDs
2022-03-13 made disarmed led not show red at all times
2022-03-13 fixed an led overwrite for the future
    [fastled-test2.ino]
2022-03-13 discarded the onboard led used for earlier tests
2022-03-13 armbutton vs button
2022-05-01 changed debounce delay to something that ⁄s actually good for stopping double clicks from registering
2022-05-01 made a new directory to test the keyboard function of the Arduino
2022-05-01 removed leds
